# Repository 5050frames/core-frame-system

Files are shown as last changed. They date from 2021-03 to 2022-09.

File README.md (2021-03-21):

# Core Development Kit

## Overview

We’ve created the Core Development Kit to make it easier for you to get started
making frame walls. It includes all the objects we used to design our frame
walls; axles, wheels, frame spacers and most importantly the Core. We’ve also
included in the CDK a sample frame wall you can use to jumpstart your design.
This wall fits 65mm wheels, which is the maximum standard wheel size.

## Getting Started

If you're new to GitHub, please take a minute to create an account so you can 
participate in discussions about the CDK. While we won't be using everything 
GitHub has to offer, we definitely will be taking your issues and suggestions 
for improvement.

Here's where to access the core-frame-system GitHub: 
https://github.com/5050frames/core-frame-system

And here's a direct download of the most current CDK: 
https://github.com/5050frames/core-frame-system/archive/refs/heads/main.zip

## Terms of Use

The Core System is open source and free for you to use to pursue your frame
design dreams. We’re licensing the system under Creative Commons so you can use
it to design any frame walls you want. Feel free to print your frame wall
designs for personal use, sell your frame wall designs for others to print,
print your frame wall designs and sell them yourself, or give them away for
free. Please leave the Cores to us though, we are not licensing the Core design
for sale, only for use when designing frame walls.

## Licensing

Core Frame System 2.0 Core, Axles and Core System 2 Logo © 2021 by Lawrence
Ingraham is licensed under CC BY-NC-ND 4.0. To view a copy of this license,
visit http://creativecommons.org/licenses/by-nc-nd/4.0/

Core System Frame Wall © 2021 by Lawrence Ingraham is licensed under CC BY 4.0.
To view a copy of this license, visit
http://creativecommons.org/licenses/by/4.0/

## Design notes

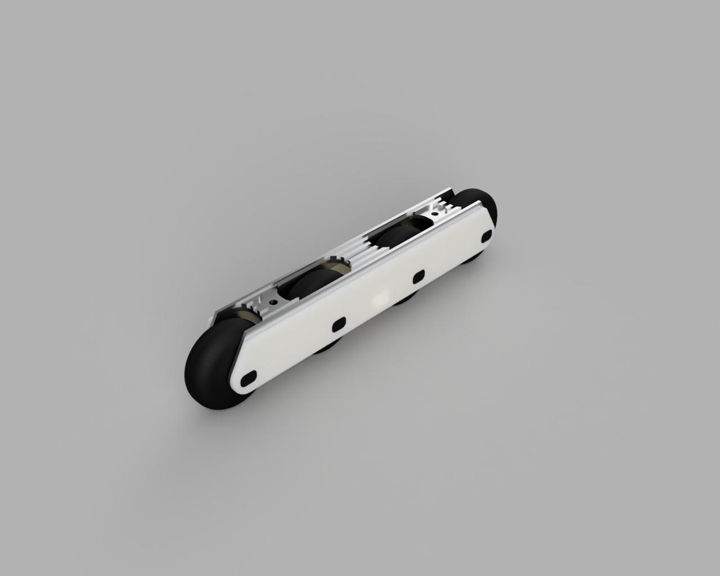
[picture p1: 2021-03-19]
Images/65mm Flat 250mm Base 1.jpg

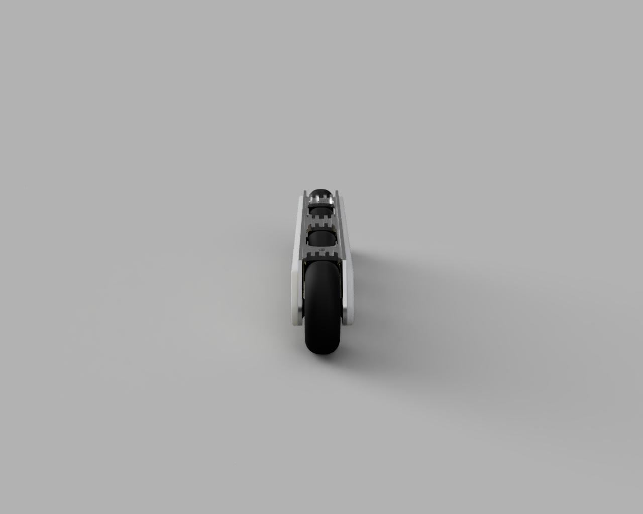
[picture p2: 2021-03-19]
Images/65mm Flat 250mm Base 3.jpg

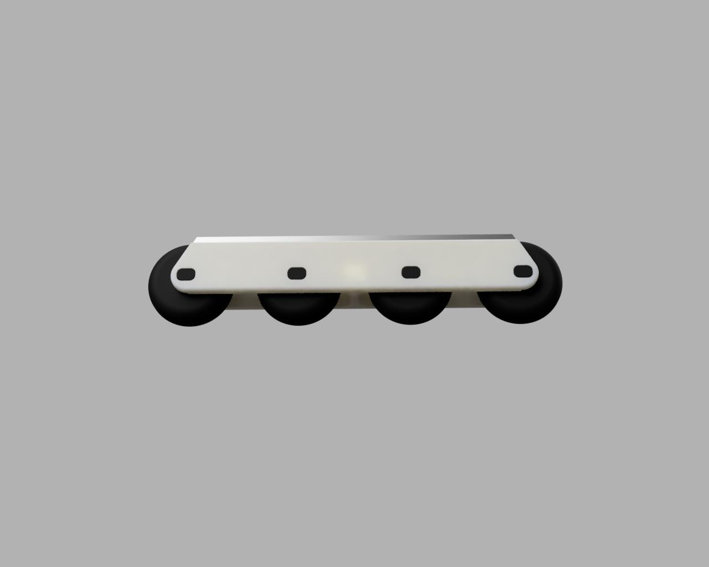
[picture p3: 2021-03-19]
Images/65mm Flat 250mm Base 2.jpg

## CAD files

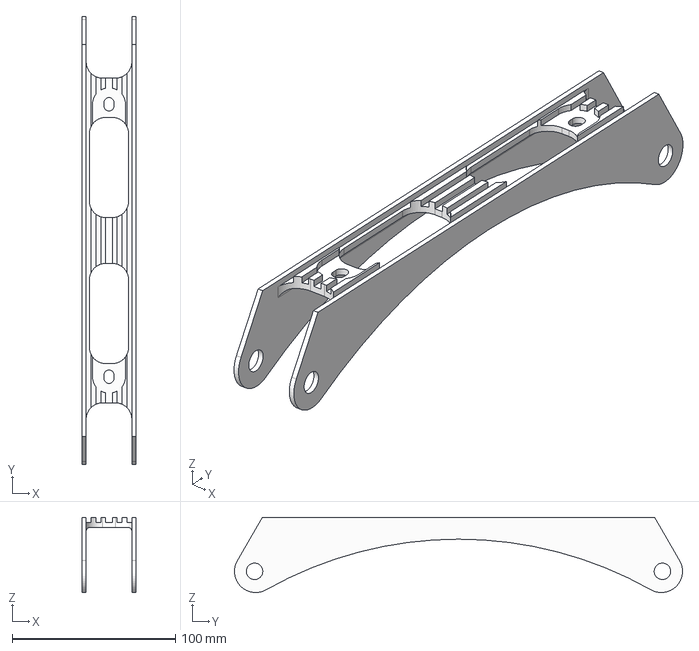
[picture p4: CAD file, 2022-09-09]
Cores/Core Medium 250mm.step
33.0 x 274.6 x 46.0 mm

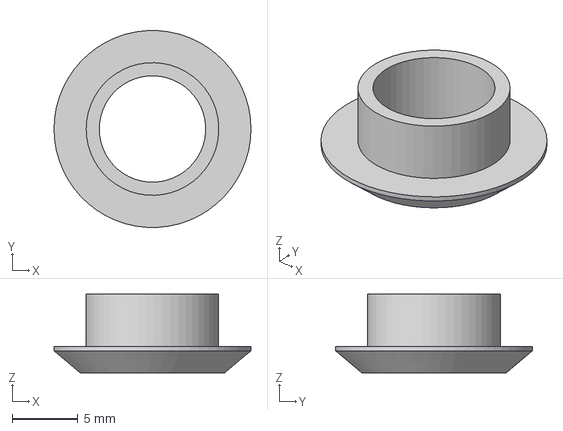
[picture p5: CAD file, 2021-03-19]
Hardware/Frame Spacer.step
15.0 x 15.0 x 6.00 mm

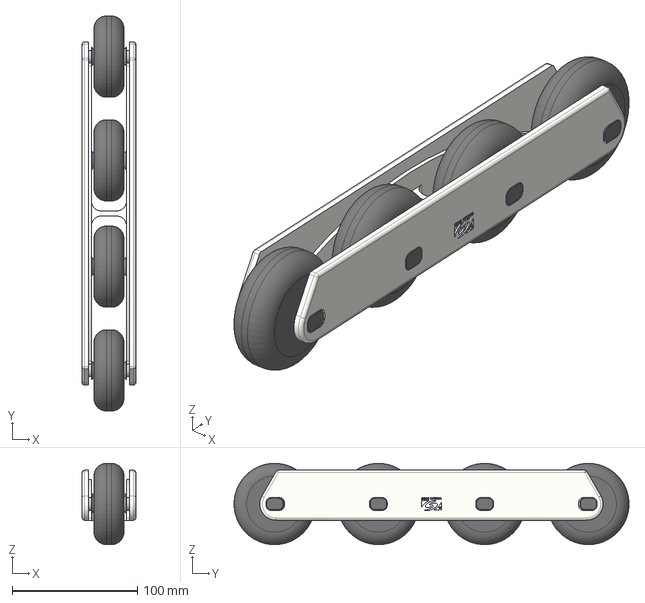
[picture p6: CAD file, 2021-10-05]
Sample Wall/Sample Wall 250mm.step
43.0 x 316.0 x 65.0 mm

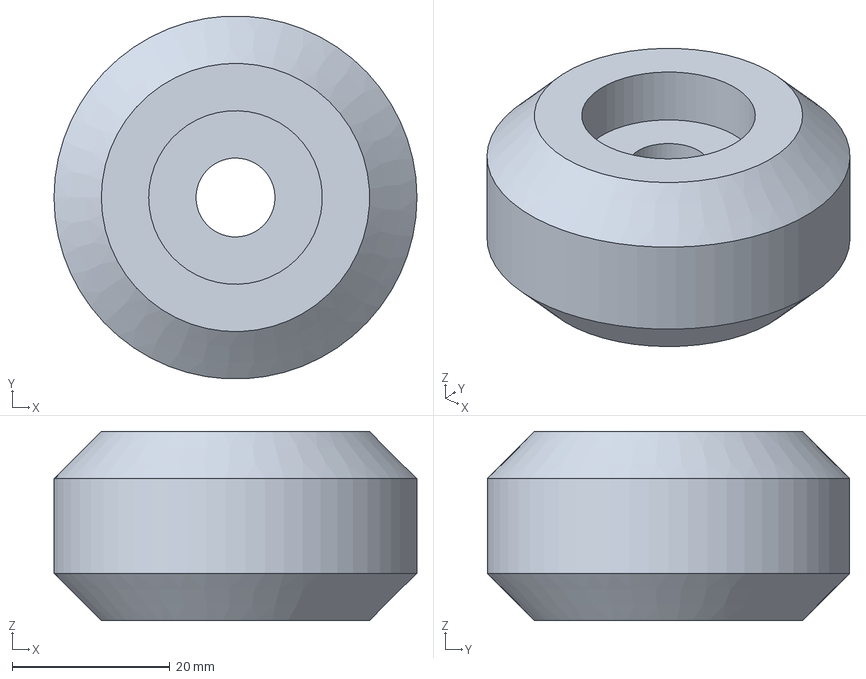
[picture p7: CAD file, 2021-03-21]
Wheels/46mm wheel.step
46.0 x 45.9 x 24.0 mm

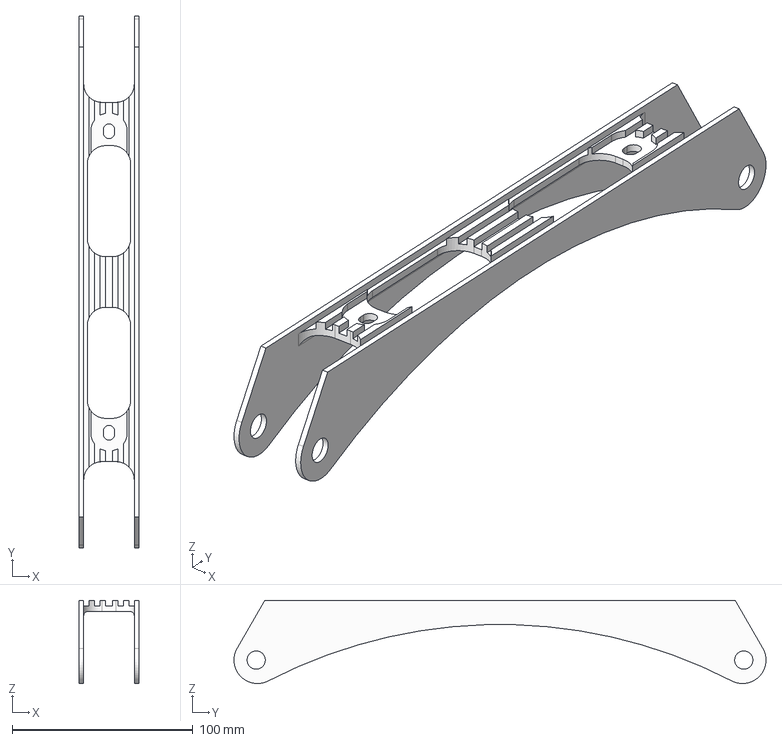
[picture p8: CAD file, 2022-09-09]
Cores/Core Large 270mm.step
33.0 x 294.6 x 46.0 mm

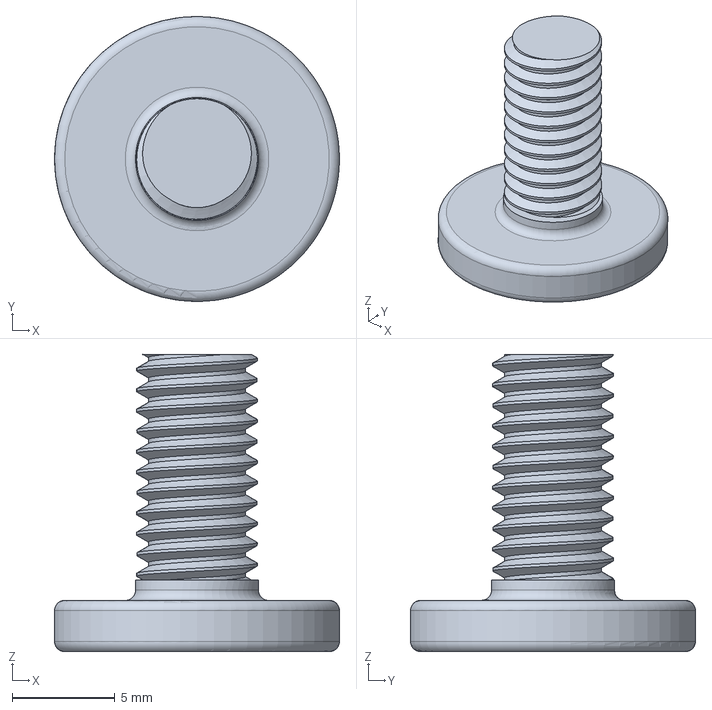
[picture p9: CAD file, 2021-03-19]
Hardware/Core Axle Male.step
13.9 x 13.9 x 14.5 mm

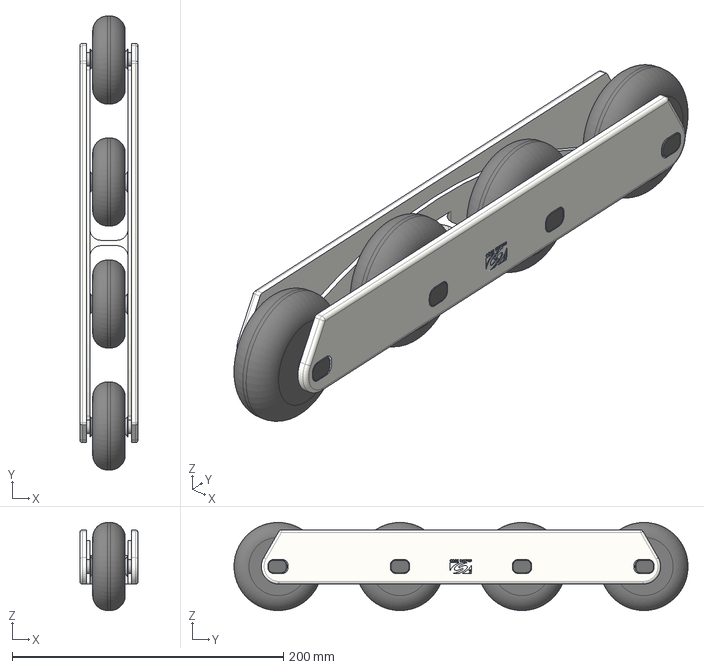
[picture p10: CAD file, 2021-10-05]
Sample Wall/Sample Wall 270mm.step
43.0 x 335.0 x 65.0 mm

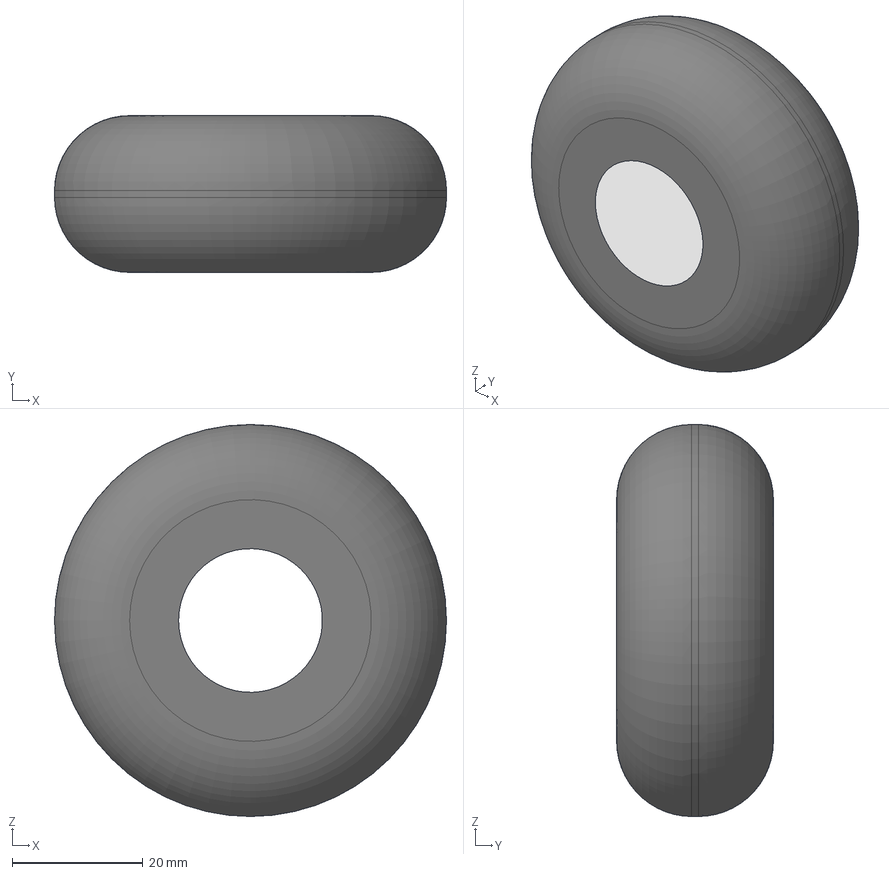
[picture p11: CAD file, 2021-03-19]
Wheels/60mm wheel.step
60.0 x 24.0 x 60.0 mm

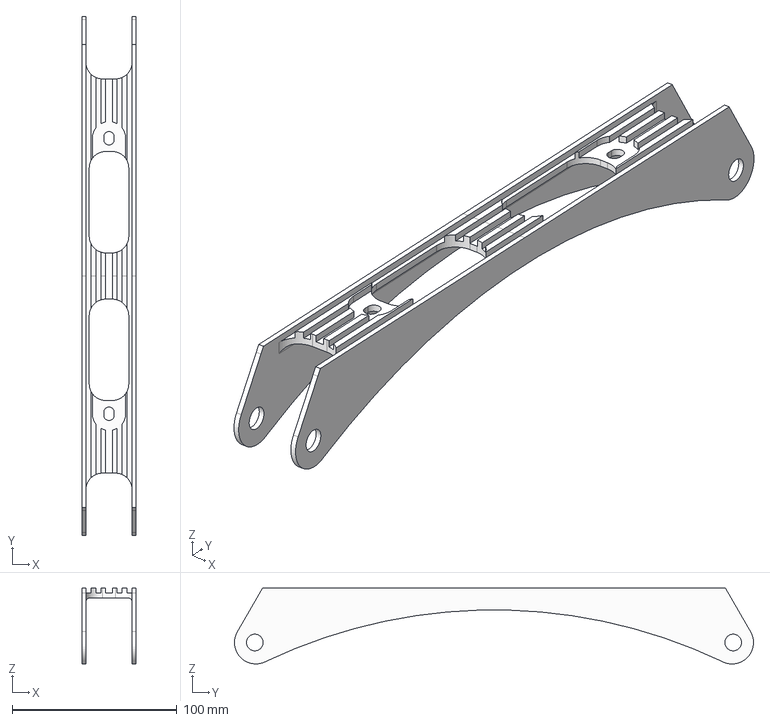
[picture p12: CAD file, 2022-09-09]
Cores/Core XLarge 290mm.step
33.0 x 314.6 x 46.0 mm

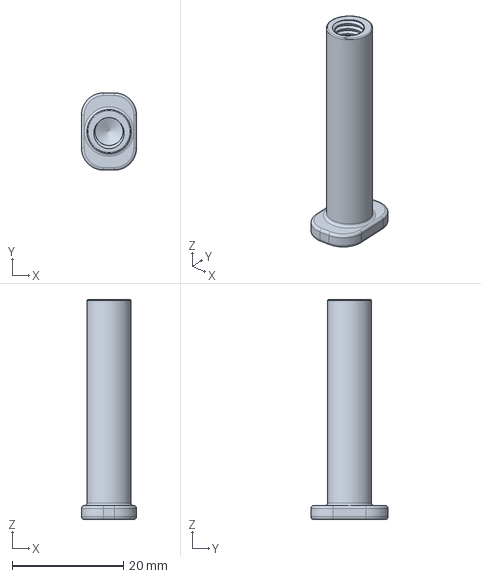
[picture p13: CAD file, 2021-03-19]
Hardware/Core Axle Female.step
9.90 x 13.9 x 39.5 mm

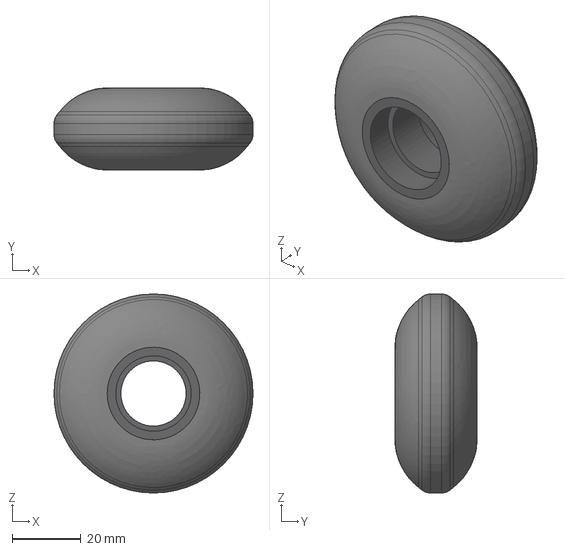
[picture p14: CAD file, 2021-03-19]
Wheels/58mm wheel.step
58.0 x 24.0 x 58.0 mm

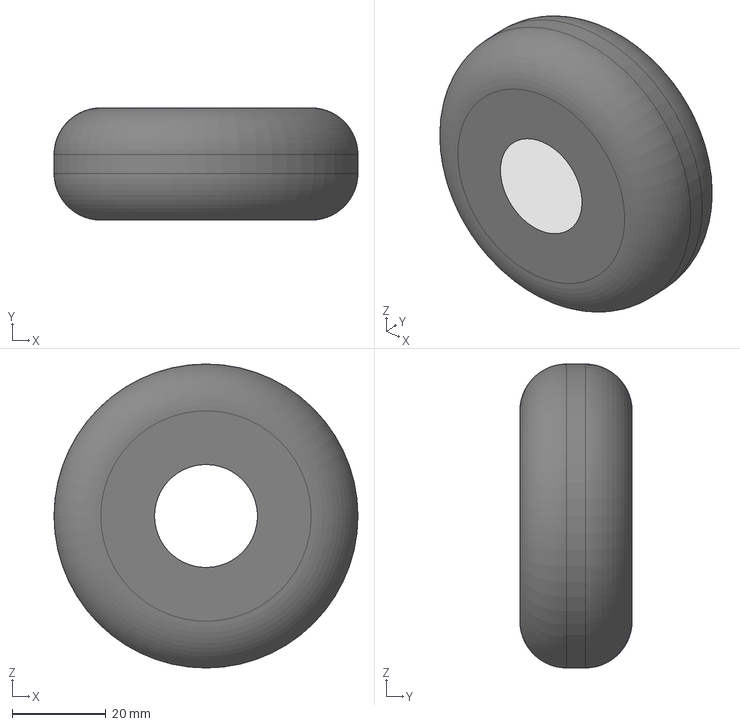
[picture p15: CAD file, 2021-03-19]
Wheels/65mm wheel.step
65.0 x 24.0 x 65.0 mm

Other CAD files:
Cores/Core Large 270mm.stl
Cores/Core Medium 250mm.stl
Cores/Core XLarge 290mm.stl
Hardware/Core Axle Female.stl
Hardware/Core Axle Male.stl
Hardware/Frame Spacer.stl
Sample Wall/Sample Wall 250mm.f3z
Sample Wall/Sample Wall 250mm.stl
Sample Wall/Sample Wall 270mm.f3z
Sample Wall/Sample Wall 270mm.stl
Wheels/46mm wheel.stl
Wheels/58mm wheel.stl
Wheels/60mm wheel.stl
Wheels/65mm wheel.stl

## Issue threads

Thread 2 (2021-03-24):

3D printers for beginners

nazroll, 2021-03-24:
I am a beginner in 3d printing. It will be helpful if i can have some information on which 3d printers that i can buy.

* Which 3D printers should I buy as a beginner?
* What kind of materials should I buy for my first sidewall?
* Where can I send my designs in Europe?

5050frames, 2021-03-26:
I hope to have a section on the Developer Portal that gives some walkthroughs for this, but until then here's some text I wrote up:

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

Closed 2021-04-24.

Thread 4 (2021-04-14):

Possible to get FreeCAD versions?

ThePatient, 2021-04-14:
Would it be possible to get FreeCAD versions of the models?

It'd be really nice if a FreeCAD version could be added for folks who don't want to use Fusion360.

I'm a beginner parametric modeler and I don't know that I have the skills needed yet to convert from .stl or .step files. From some googling, it looks like .f3d conversion is an area of active development.

If I do manage to convert them on my own, would a PR be welcome to add them to the repo?

5050frames, 2021-04-15:
That would be awesome! I'm all for using whatever tools you prefer. I don't have any experience with FreeCAD, but if you have any luck converting the STEP files over please open a PR or just let me know and I'll update the kit. Thanks for the interest.

Flowwie, 2021-09-07:
I will be happy to help with this issue, I'm running a FreeCAD consulting business, so everybody interested here to bring the 5050 core frame system feel free to contact me

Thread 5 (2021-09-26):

Print skrinkage/warpage

hunterstabler, 2021-09-26:
Hi,
Just finished my first test print of a frame design for the Core system. I have a fair amount of experience printing with stereolithography resin, which is quite mathematically accurate down to 100th of mm, but much less experience with FDM printing. I am wondering if overall dimensions need to be scaled up, hole diameters scaled up etc to account for shrinkage. My print seemed to shrink a fair amount at the ends and pulled up. It was 20% infill and PLA+ for the test. I am using a Creality CR10 S pro and Cura. I am also modeling in Rhino3D, so there is a small chance I am getting some discrepancies converting Fusion files to STL to 3DM geometry, but I kind of doubt it because my file measurements match my caliper measurements of the 50/50 Core frame and hardware within 10ths of mm. Any breakdown of bed temperature, layer height/resolution, print speed, brim, supports, etc would be very helpful. Also, if you are scaling up your holes for frame spacers, what diameter are you using?

HeXiBLiTz, 2021-09-27:
I have been using a +0.2mm on the holes and internal width with 0.5mm around the core or using the CDK files the outer offset line of the core sketch. I hope this helps.
shrinkage will happen I recently calibrated my machine to print more accurately also (Previously I was printing at 271 and 251mm axle holes and the core fitting fine but that meant my machine was technically printing innacuratly)

vnznconcepts, 2022-04-29:
My suggestion is to adjust the 3D model to account for shrinkage. Also consider the line width, if not a perfect multiple of the dimension of the feature, Cura will compensate by rounding down to the nearest multiple of that features width. Holes printed on a vertical plane will never be perfectly round. Even with support material (although soluble support gets you closer). I plan to make drill jigs to ream axel/bolt holes to final size.

Test by using smaller cross section chunks (rather than full frame walls), printed in the same orientation as the full print. Test fit/measure, then adjust until you are happy, then do a full print. Saves time, material and $$$.

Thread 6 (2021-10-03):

Cura Profiles

hunterstabler, 2021-10-03:
If anyone would be willing to share their Cura profile for framewall printing and upload it here on Github, that would be a big help. I understand that you may have spent a lot of time, skill and effort dialing that in. To save and export a profile just click on the Profile drop down under the Print Settings > Create Custom Profile from current settings. Then in the top bar you can go to Preferences > Profiles > Export. So if you decide to upload your Cura print profile, maybe give a brief description of your printer, any mods or anything you have done to troubleshoot or dial in your machine. This is probably obvious to anyone who has done a lot of printing, but for me getting the first layer dialed in by lowering the Z a bit during the first layer printing to get it properly squished down has helped prevent failure. I am also planning on building an enclosure for the machine to regulate temperature and prevent breezes from my window from interfering. If anyone out there is using CAM features of Fusion360 to program G-code for a CNC router, I would be happy to share my settings for that or my settings in RhinoCAM.

vnznconcepts, 2022-04-29:
I'm sure you figured out your settings by now. I think Cura settings would be on a very individual basis, depending on material used and your specific printer. The best way to figure it out is just by using your printer and learning how different settings affect your print.

Manufacturers suggested print settings and or Printer presets are a good place to start.  From there adjusting Temps and flow Rate are easy adjustments. At 100% infill you should be watching to see that there are no voids or gaps between lines, especially where the outer walls meet the infill. There is a setting to allow for some overlap called "Infill Overlap Percentage". This will help firmly connect the wall to the infill and add strength imo.

michaeltrilford, 2022-05-06:
Is there a dedicated discord for chatting with the community here? It's so hard to get questions answered. All the touch points are a bit scattered.

msdosfx, 2022-05-06:
>

I don't think there is a chat. I am not on Discord. I know B2Blading is on Slack, but I also really dislike Slack b/c of ownership and privacy policies. In the spirit of open source, I could set up a Matrix chat room for the Core 2.0 system developers, but I don't know if any of you are on Matrix yet. A Matrix room can be bridged to Slack, Discord and Telegram. Centralized servers that operate on the business model of surveillance capitalism are not really cool.

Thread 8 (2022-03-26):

Recommended Mac 3D software (Free/Paid)

michaeltrilford, 2022-03-26:
I would like to explore some ideas I have with the C O R E system, but I'm unsure of any good software for MAC.

Any recommendation will be greatly appreciated.

5050frames, 2022-04-13:
Hey Michael,

Sorry for the delayed response, just getting caught up. We mostly recommend Fusion 360 for a cross platform solution. That's what I'm using for all the 50/50 parts now.

michaeltrilford, 2022-04-22:
Fantastic, that’s what I’m using too.

However, the files I imported from this GitHub are not working files? Maybe it is intentional, but I keen to access the ‘sketch’ aspects of the file, so I can ensure the print part is correct.

I’m very new to 3D, but this is what I managed to put together so far. Also printing a test!

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

Closed 2022-04-13.

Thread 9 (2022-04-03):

Technical drawings

michaeltrilford, 2022-04-03:
I'm struggling to measure/find the specific measurements of the hardware.

E.g. What is the diameter of the bolts (Is it 8.234mm?)

I was wondering if there is a way to find this information today, if not, technical drawings (Agnostic to a drawing program) would be good to add to this repo.

Context about my situation:

- I'm using Fusion360
- I'm converting Mesh to the preferred modelling method, as I can't edit the current models

5050frames, 2022-04-13:
I believe the axles in the CDK are the production axles. So the .step file is what we sent to the factory for making the toolings.

michaeltrilford, 2022-04-22:
Yeh, I was keen to start with a wall and remove the logo.

I actually couldn’t do that, I can take a look a again as I’ve learnt the program.

Unsure if I could access history / sketch and remove the core system logo

HeXiBLiTz, 2022-04-22:
Hey Michael,

You can access all of the sketches through the Sample wall files. to pull them to your own project simple open the sketch you want (so it's editable) select it all and Ctrl+c then create a new sketch in your own project and Ctrl+V to paste. (Sorry I don't know the key binds for copy and paste on Mac but hopefully, you get the idea :)
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

michaeltrilford, 2022-04-22:
I found the logo really hard to select and extrude it back into shape.

Maybe I will be able to do it, after the learning the programs. I will take a look and see if I wasted my time building my own wall from scratch. Haha.

michaeltrilford, 2022-04-22:
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

Your one looks like a working file. Interesting

HeXiBLiTz, 2022-04-22:
the sketch for the logo in on the centre plane (essentially between the walls in the middle. you'd have to manually select each segment by clicking the sketch so hiding the walls etc whilst you do that will help make it easier to select which parts you want to extrude.
That file is the sample wall file in this repo, there is also a core .Step file.
and on the note of of building your own from scratch that's a good thing, use the CDK as references and reverse engineer the files/build your own it'll help you learn the software and have a understand of how it is all made :)

michaeltrilford, 2022-04-22:
> the sketch for the logo is on the centre plane (essentially between the walls in the middle. you'd have to manually select each segment by clicking the sketch so hiding the walls etc whilst you do that will help make it easier to select which parts you want to extrude.
> That file is the sample wall file in this repo, there is also a core .Step file.
> and on the note of building your own from scratch that's a good thing, use the CDK as references and reverse engineer the files/build your own it'll help you learn the software and have a understanding of how it is all made :)

Thank you mate! I agree, it did help. I didn’t do any tutorials either. Quite intuitive an application!

Here’s the progression! Based around Arlo’s NFT project:
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

Closed 2022-04-13.

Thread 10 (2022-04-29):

Developer Core Only/Hardware Kits to purchase?

vnznconcepts, 2022-04-29:
I'm wondering if just the Core and hardware are available for purchase? I believe I've seen the hardware available for purchase, but to get cores, I have only seen them for purchase WITH walls. Injection molded or pre-printed from developers.

As a new developer, I'd love the option to purchase only the Cores, since I'd be printing and using my own walls.

I emailed Lawrence about this but waiting on a reply still.

michaeltrilford, 2022-05-06:
Same here. I'm a little stuck.

msdosfx, 2022-05-06:
go to the 50/50 website and contact Law via the email contact link. He will sell cores and hardware when he has them available.

msdosfx, 2022-05-06:
I am guessing Law is just busy. He has a lot of jobs. I got an extra set of cores from him a month or so ago and a lot of extra hardware

vnznconcepts, 2022-05-16:
Lawrence got back to me via email about a week ago. He said a big shipment should be on a boat at the end of the month and in hand late June.  Fingers crossed...

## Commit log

2021-03-19 Initial Commit of Preview Release
    [58mm wheel.step, 58mm wheel.stl, 60mm wheel.step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]
2021-03-19 Add 46mm Wheel and Update Readme
    [46mm wheel.step, 46mm wheel.stl]
2021-03-21 Updated Core drawings with correct origin
    [Core Large 270mm.step, Core Large 270mm.stl, Core Medium 250mm.step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]
2021-10-05 Update Core and Sample Walls
    ### Cores
    * Updated to 250mm and 270mm to match production Core System Frames
    ### Sample Walls
    * Updated to 250mm and 270mm to match production Core System Frames
    * Added .5mm buffer to outside axles to allow for improved compatibility with Core tolerances
    [Core Large 270mm.step, Core Large 270mm.stl, Core Medium 250mm.step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]
2022-09-09 Update Core mounting holes; Add 290mm Core
    [Core Large 270mm.step, Core Large 270mm.stl, Core Medium 250mm.step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]
